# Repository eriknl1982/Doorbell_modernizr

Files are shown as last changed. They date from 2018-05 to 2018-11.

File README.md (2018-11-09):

Imgur

This repository contains sample code and eagle/gerber/STL files for the Doorbell Modernizr I sell on tindie: https://www.tindie.com/products/ErikLemcke/doorbell-modernizr/

The Doorbell Modernizr is a device that can transform your ordinary doorbell (running on 8 - 24v ac) into a "smart" wifi doorbell.
Whenever someone presses your doorbell, the Doorbell Modernizr can send a signal to your home automation system (currently supported: Home assistant, Domoticz and Openhab).

If you want to program the device yourself (for example with the Arduino IDE),provide it with power, plug in a ftdi module and set the dipswitch on the pcb to on.

I use the folowing settings for programming:

- Board: Generic EP8266 module
- Flash mode: QIO
- Flash size: 512K (64K SPIFFS)
- Debugging port: Disabled
- Debug level: None
- IwIP variant: V2 lower memory
- reset method: ck
- crystal frequency: 26Mhz
- Flash frequency: 40Mhz
- CPU frequency: 80Mhz
- Builtin led: 2
- Upload speed: 115200
- Erase flash: Only sketch

If you are going to build it yourself, you will need the folowing parts:

#### To assemble this board, you will need the following parts:
- 1x ESP12f module [(sample)](https://www.aliexpress.com/item/ESP8266-Remote-Serial-WIFI-Transceiver-Wireless-Module-Esp-12-AP-STA-TOP/32646271039.html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,searchweb201602_4_10152_10709_10151_10065_10344_10068_5722815_10342_10343_10340_5722915_10341_5722615_10696_10084_10083_10618_10304_10710_10307_10301_5722715_5711215_10059_308_100031_10103_10624_10623_10622_5711315_5722515_10621_10620,searchweb201603_36,ppcSwitch_5&algo_expid=2d4aea06-a96e-40a3-a231-87c2b62a80c4-1&algo_pvid=2d4aea06-a96e-40a3-a231-87c2b62a80c4&transAbTest=ae803_2&priceBeautifyAB=0)
- 4x 10k resitor, smd size 1206 [(sample)](https://www.aliexpress.com/item/Free-Shipping-100PCS-1206-10K-10K-OHM-1-smd-resistor/1090806202.html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,searchweb201602_4_10152_10709_10151_10065_10344_10068_5722815_10342_10343_10340_5722915_10341_5722615_10696_10084_10083_10618_10304_10710_10307_10301_5722715_5711215_10059_308_100031_10103_10624_10623_10622_5711315_5722515_10621_10620,searchweb201603_36,ppcSwitch_5&algo_expid=709525b8-8593-455c-8efa-07c3f3ce8228-0&algo_pvid=709525b8-8593-455c-8efa-07c3f3ce8228&transAbTest=ae803_2&priceBeautifyAB=0)
- 1x 10k resitor, thru hole [(sample)](https://www.aliexpress.com/store/product/100pcs-set-1-4W-Resistance-1-Metal-Film-Resistor-Pack-Assorted-Kit-1K-2K-4-7K/1504763_32861819464.html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,searchweb201602_4_10152_10151_10065_10344_10068_10342_10343_10340_10341_10696_10084_10083_10618_10304_10307_10820_10821_10301_10843_10059_100031_10103_10624_10623_10622_10621_10620,searchweb201603_51,ppcSwitch_5&algo_expid=e3fd0740-6222-418d-9183-fe36bdfb2f1d-0&algo_pvid=e3fd0740-6222-418d-9183-fe36bdfb2f1d&transAbTest=ae803_2&priceBeautifyAB=0)
- 1x 330r resitor, smd size 1206 [(sample)](https://www.aliexpress.com/item/100Pcs-1206-SMD-resistor-0R-10M-1-2W-0-1-10-100-150-220-330-ohm/32847115923.html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,searchweb201602_4_10152_10709_10151_10065_10344_10068_5722815_10342_10343_10340_5722915_10341_5722615_10696_10084_10083_10618_10304_10710_10307_10301_5722715_5711215_10059_308_100031_10103_10624_10623_10622_5711315_5722515_10621_10620,searchweb201603_36,ppcSwitch_5&algo_expid=03d36d71-9210-4daa-ba6d-0d927a84b877-0&algo_pvid=03d36d71-9210-4daa-ba6d-0d927a84b877&transAbTest=ae803_2&priceBeautifyAB=0)
- 1x 1p dip switch [(sample)](https://www.aliexpress.com/item/10PCS-Lot-DIP-Switch-1P-2-54mm-Toggle-Switch-Red-Snap-Switch/32778200806.html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,searchweb201602_4_10152_10709_10151_10065_10344_10068_5722815_10342_10343_10340_5722915_10341_5722615_10696_10084_10083_10618_10304_10710_10307_10301_5722715_5711215_10059_308_100031_10103_10624_10623_10622_5711315_5722515_10621_10620,searchweb201603_36,ppcSwitch_5&algo_expid=cc64cbff-a764-4662-8452-5fbc674b3830-3&algo_pvid=cc64cbff-a764-4662-8452-5fbc674b3830&transAbTest=ae803_2&priceBeautifyAB=0)
- 2x tactile switch [(sample)](https://www.aliexpress.com/item/THGS-25pcs-Round-Pushbutton-4-Pins-SMD-SMT-Momentary-Tactile-Switch/32721411394.html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,searchweb201602_4_10152_10709_10151_10065_10344_10068_5722815_10342_10343_10340_5722915_10341_5722615_10696_10084_10083_10618_10304_10710_10307_10301_5722715_5711215_10059_308_100031_10103_10624_10623_10622_5711315_5722515_10621_10620,searchweb201603_36,ppcSwitch_5&algo_expid=72ad9c0a-894e-4d0d-a650-c844d18cb295-12&algo_pvid=72ad9c0a-894e-4d0d-a650-c844d18cb295&transAbTest=ae803_2&priceBeautifyAB=0)
- 1x 470uf capacitor [(sample)](https://www.aliexpress.com/item/SMD-electrolytic-capacitor-470UF-6-3V-6-3-7-7MM-VT-type-chip-polarity-temperature-105/32814865187.html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,searchweb201602_4_10152_10709_10151_10065_10344_10068_5722815_10342_10343_10340_5722915_10341_5722615_10696_10084_10083_10618_10304_10710_10307_10301_5722715_5711215_10059_308_100031_10103_10624_10623_10622_5711315_5722515_10621_10620,searchweb201603_36,ppcSwitch_5&algo_expid=fa08a327-d750-4922-8d0c-8a368b171ecc-13&algo_pvid=fa08a327-d750-4922-8d0c-8a368b171ecc&transAbTest=ae803_2&priceBeautifyAB=0)
- 1x 100nf capacitor, SMD size 1206 [(sample)](https://www.aliexpress.com/item/Free-Shipping-100PCS-1206-104-100NF-0-1UF-1206-SMD-capacitance/1096160798.html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,searchweb201602_4_10152_10709_10151_10065_10344_10068_5722815_10342_10343_10340_5722915_10341_5722615_10696_10084_10083_10618_10304_10710_10307_10301_5722715_5711215_10059_308_100031_10103_10624_10623_10622_5711315_5722515_10621_10620,searchweb201603_36,ppcSwitch_5&algo_expid=ae9db756-53ad-4fca-853d-d6855f03eda6-0&algo_pvid=ae9db756-53ad-4fca-853d-d6855f03eda6&transAbTest=ae803_2&priceBeautifyAB=0)
- 1x 2pin screw terminal [(sample)](https://www.aliexpress.com/item/20-PCS-KF301-5-0-2P-blue-KF301-3P-Pitch-5-0mm-KF301-2P-Straight-Pin/32833138976.html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,searchweb201602_4_10152_10709_10151_10065_10344_10068_5722815_10342_10343_10340_5722915_10341_5722615_10696_10084_10083_10618_10304_10710_10307_10301_5722715_5711215_10059_308_100031_10103_10624_10623_10622_5711315_5722515_10621_10620,searchweb201603_36,ppcSwitch_5&algo_expid=dd191ab4-0937-468a-a91b-19ac53064bd2-2&algo_pvid=dd191ab4-0937-468a-a91b-19ac53064bd2&transAbTest=ae803_2&priceBeautifyAB=0)
- 1x 6pin female header [(sample)](https://www.aliexpress.com/item/40pcs-2-54MM-6Pin-11MM-Long-Needle-Female-Header-Strip-Stackable-Header-for-arduino-W5100-6p/32668087711.html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,searchweb201602_4_10152_10709_10151_10065_10344_10068_5722815_10342_10343_10340_5722915_10341_5722615_10696_10084_10083_10618_10304_10710_10307_10301_5722715_5711215_10059_308_100031_10103_10624_10623_10622_5711315_5722515_10621_10620,searchweb201603_36,ppcSwitch_5&algo_expid=c0a98dbf-f354-486c-be51-a9068dfd1d38-12&algo_pvid=c0a98dbf-f354-486c-be51-a9068dfd1d38&transAbTest=ae803_2&priceBeautifyAB=0)
- 1x HT7333 LDO [(sample)](https://www.aliexpress.com/item/10PCS-HT7333-A-SOT-89-HT7333-1-SOT89-HT7333-7333-1-SMD-7333A-1-new-and/32818420909.html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,searchweb201602_4_10152_10709_10151_10065_10344_10068_5722815_10342_10343_10340_5722915_10341_5722615_10696_10084_10083_10618_10304_10710_10307_10301_5722715_5711215_10059_308_100031_10103_10624_10623_10622_5711315_5722515_10621_10620,searchweb201603_36,ppcSwitch_5&algo_expid=5d51c538-7dd5-42bd-8e93-c66127f056bf-0&algo_pvid=5d51c538-7dd5-42bd-8e93-c66127f056bf&transAbTest=ae803_2&priceBeautifyAB=0)
- 1x 1N4148 diode, smd size 1206 [(sample)](https://www.aliexpress.com/item/100pcs-1206-1N4148W-T4-1N4148-SOD-123-Switching-Diode/32354597825.html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,searchweb201602_4_10152_10709_10151_10065_10344_10068_5722815_10342_10343_10340_5722915_10341_5722615_10696_10084_10083_10618_10304_10710_10307_10301_5722715_5711215_10059_308_100031_10103_10624_10623_10622_5711315_5722515_10621_10620,searchweb201603_36,ppcSwitch_5&algo_expid=7cf2de10-d2b9-41eb-a268-300ace100396-0&algo_pvid=7cf2de10-d2b9-41eb-a268-300ace100396&transAbTest=ae803_2&priceBeautifyAB=0)
- 1x PC817 Optocoupler [(sample)](https://www.aliexpress.com/item/100PCS-PC817C-DIP-PC817-C-DIP4-PC817-C-new-and-original-IC-free-shipping/32847601895.html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,searchweb201602_4_10152_10709_10151_10065_10344_10068_5722815_10342_10343_10340_5722915_10341_5722615_10696_10084_10083_10618_10304_10710_10307_10301_5722715_5711215_10059_308_100031_10103_10624_10623_10622_5711315_5722515_10621_10620,searchweb201603_36,ppcSwitch_5&algo_expid=e8d061c3-7004-462e-899c-a522d5885630-1&algo_pvid=e8d061c3-7004-462e-899c-a522d5885630&transAbTest=ae803_2&priceBeautifyAB=0)
- 1x 5.5 x 2.1 mm Female DC Power Jack Plug Socket [sample](https://www.aliexpress.com/item/10Pcs-PCB-Mount-5-5-x-2-1-mm-Female-DC-Power-Jack-Plug-Socket-Connector/32813661863.html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,searchweb201602_4_10152_10709_10151_10065_10344_10068_5722815_10342_10343_10340_5722915_10341_5722615_10696_10084_10083_10618_10304_10710_10307_10301_5722715_5711215_10059_308_100031_10103_10624_10623_10622_5711315_5722515_10621_10620,searchweb201603_36,ppcSwitch_5&algo_expid=b89433cb-84ea-4f2c-b110-90657c1acf5a-26&algo_pvid=b89433cb-84ea-4f2c-b110-90657c1acf5a&transAbTest=ae803_2&priceBeautifyAB=0)
- 1x 5v power supply [sample](https://www.aliexpress.com/item/1PCS-High-quality-AC-100V-240V-Converter-Switching-power-adapter-DC-5V-2A-2000MA-Supply-EU/32496043021.html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,searchweb201602_4_10152_10709_10151_10065_10344_10068_5722815_10342_10343_10340_5722915_10341_5722615_10696_10084_10083_10618_10304_10710_10307_10301_5722715_5711215_10059_308_100031_10103_10624_10623_10622_5711315_5722515_10621_10620,searchweb201603_36,ppcSwitch_5&algo_expid=0f10a11c-3fea-4ce8-9680-a6fa20d2b76d-3&algo_pvid=0f10a11c-3fea-4ce8-9680-a6fa20d2b76d&transAbTest=ae803_2&priceBeautifyAB=0)
- 1x MB6S bridge rectifier [sample](https://www.aliexpress.com/item/Free-shipping-20pcs-600V-0-5A-SOP-4-SMD-rectifier-diode-bridge-mb6s/32336867082.html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,searchweb201602_3_10152_10151_10065_10344_10068_5723115_5722815_10342_10343_10340_5722915_10341_5722615_10696_10084_10083_10618_10304_10307_10820_10301_10821_5722715_10843_10059_100031_10103_10624_10623_10622_5722515_10621_10620,searchweb201603_50,ppcSwitch_5&algo_expid=d8bc8f3c-cd8b-4e61-a706-30cb63aab87a-0&algo_pvid=d8bc8f3c-cd8b-4e61-a706-30cb63aab87a&transAbTest=ae803_2&priceBeautifyAB=0)

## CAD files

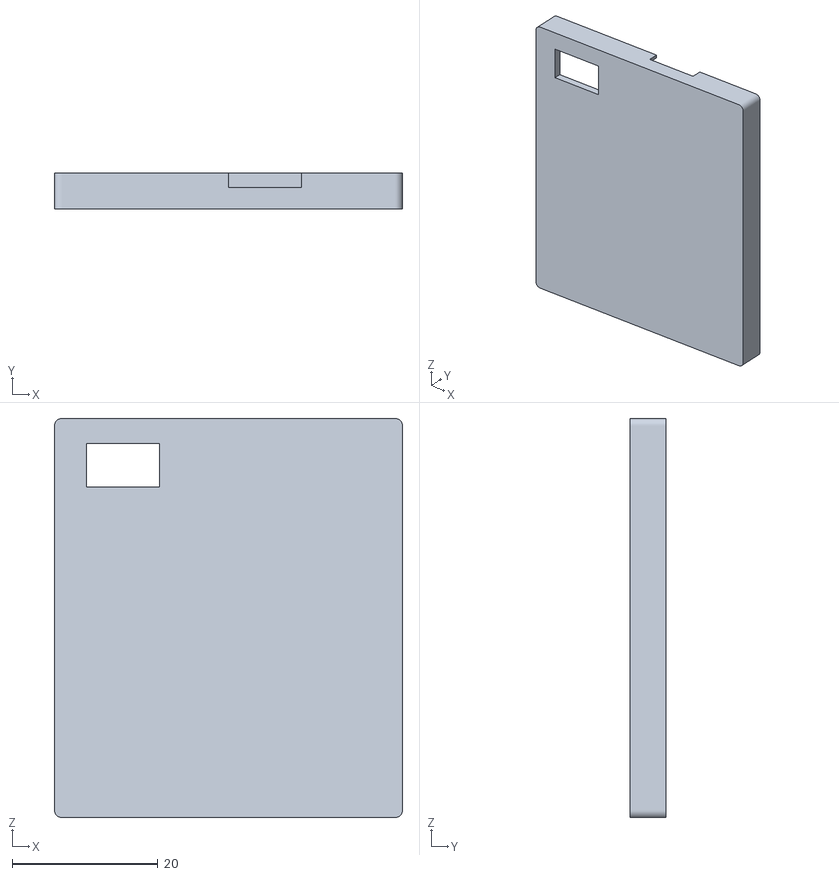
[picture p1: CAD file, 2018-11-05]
3d print housing files/for v2.0/top.STL
47.8 x 5.00 x 54.8

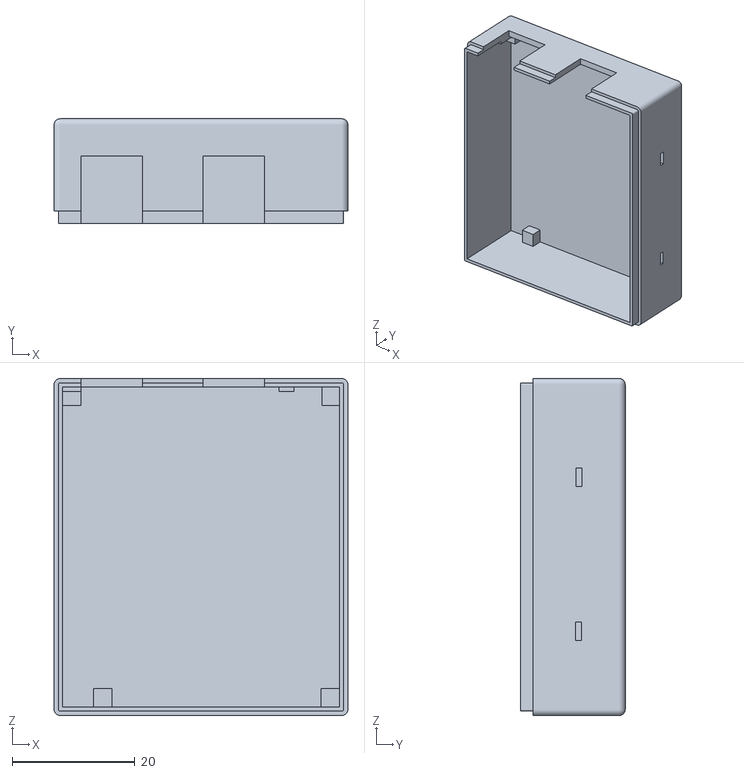
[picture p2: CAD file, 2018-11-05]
3d print housing files/for v2.0/base.STL
47.8 x 17.0 x 54.8

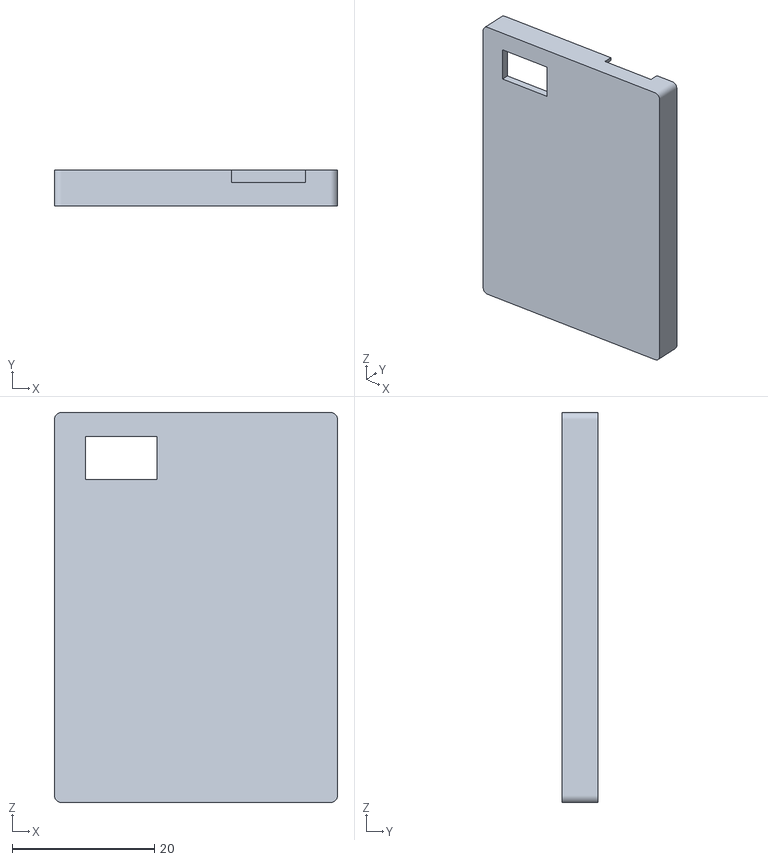
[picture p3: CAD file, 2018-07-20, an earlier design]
3d print housing files/for v1.1/top.STL
39.8 x 5.00 x 54.8

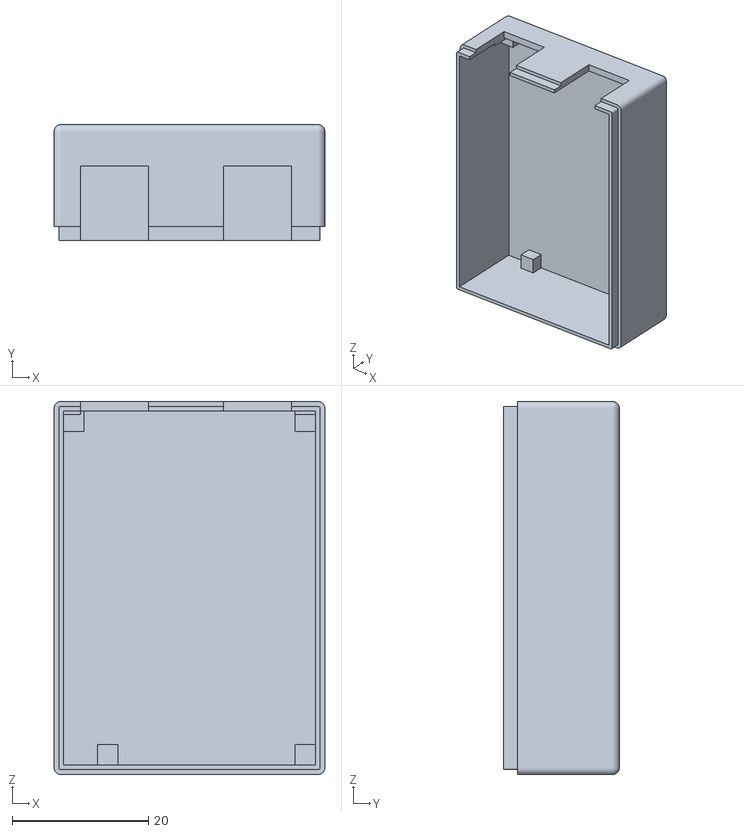
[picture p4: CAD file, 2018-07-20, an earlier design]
3d print housing files/for v1.1/base.STL
39.8 x 17.0 x 54.8

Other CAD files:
3d print housing files/for v1.2 & 1.2a/base.STL
3d print housing files/for v1.2 & 1.2a/top.STL

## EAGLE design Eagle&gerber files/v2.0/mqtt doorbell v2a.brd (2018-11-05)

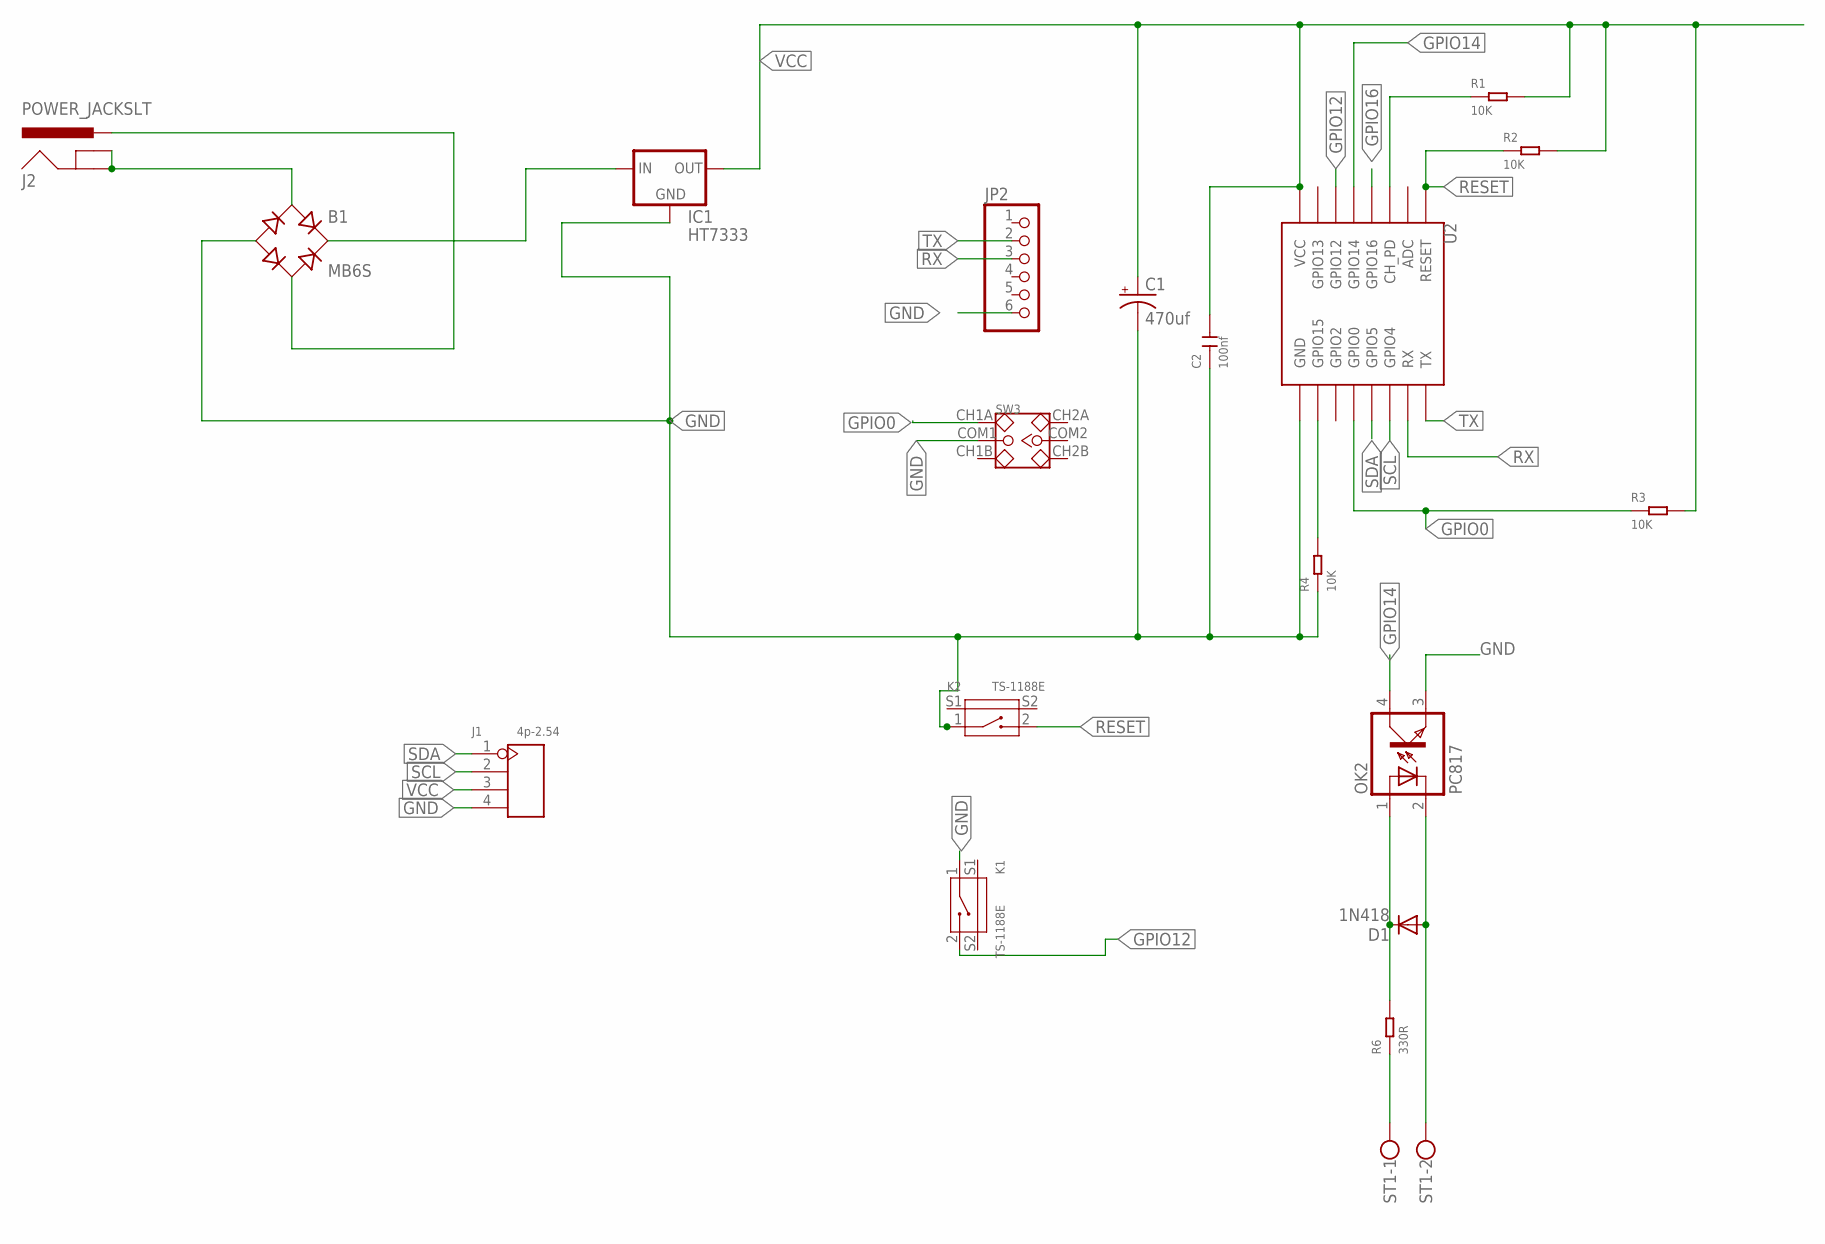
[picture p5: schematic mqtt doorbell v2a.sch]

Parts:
B1: MB6S; SOIC-4
C1: 470uf; PANASONIC_D
C2: 100nf; C0603
D1: 1N418; SOD-123_MINI-SMA
IC1: HT7333; SOT-89
J1: 4p-2.54; H4-2.54
J2: POWER_JACKSLT; POWER_JACK_SLOT
JP2: PINHD-1X6; 1X06
K1, K2: TS-1188E; SW4-SMD-7.0X3.5X3.5MM-90D
OK2: PC817; SOP-4-2.54
R1, R2, R3, R4: 10K; R0603
R6: 330R; R0603
ST1: W237-102
SW3: SMD-TOGGLE-SWITCH-2CH(2X3P-7X3.5MM); SW6-2.54-SMD-7.0X3.5X1.5MM
U2: ESP12SMD; ESP12-SMD

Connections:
GND: B1.-, C1.-, C2.1, IC1.2 (GND), J1.4, JP2.6, K1.1, K2.1, OK2.3 (EMIT), R4.1, SW3.COM1, U2.GND
GPIO0: R3.1, SW3.CH1A, U2.GPIO0
GPIO12: K1.2, U2.GPIO12
GPIO14: OK2.4 (COL), U2.GPIO14
GPIO16: U2.GPIO16
L1: B1.+, IC1.3 (IN), IC1.4 (IN)
unnamed: B1.~2 (AC2), J2.PWR
unnamed: D1.C, OK2.1 (A), R6.2
unnamed: D1.A, OK2.2 (C), ST1.2
unnamed: R1.1, U2.CH_PD
unnamed: R6.1, ST1.1
unnamed: R4.2, U2.GPIO15
unnamed: B1.~1 (AC1), J2.GND@1 (GNDBREAK), J2.GND@2 (GND)
RESET: K2.2, R2.1, U2.RESET
RX: JP2.3, U2.RXD0 (RX)
SCL: J1.2, U2.GPIO4
SDA: J1.1, U2.GPIO5
TX: JP2.2, U2.TXD0 (TX)
VCC: C1.+, C2.2, IC1.1 (OUT), J1.3, R1.2, R2.2, R3.2, U2.VCC

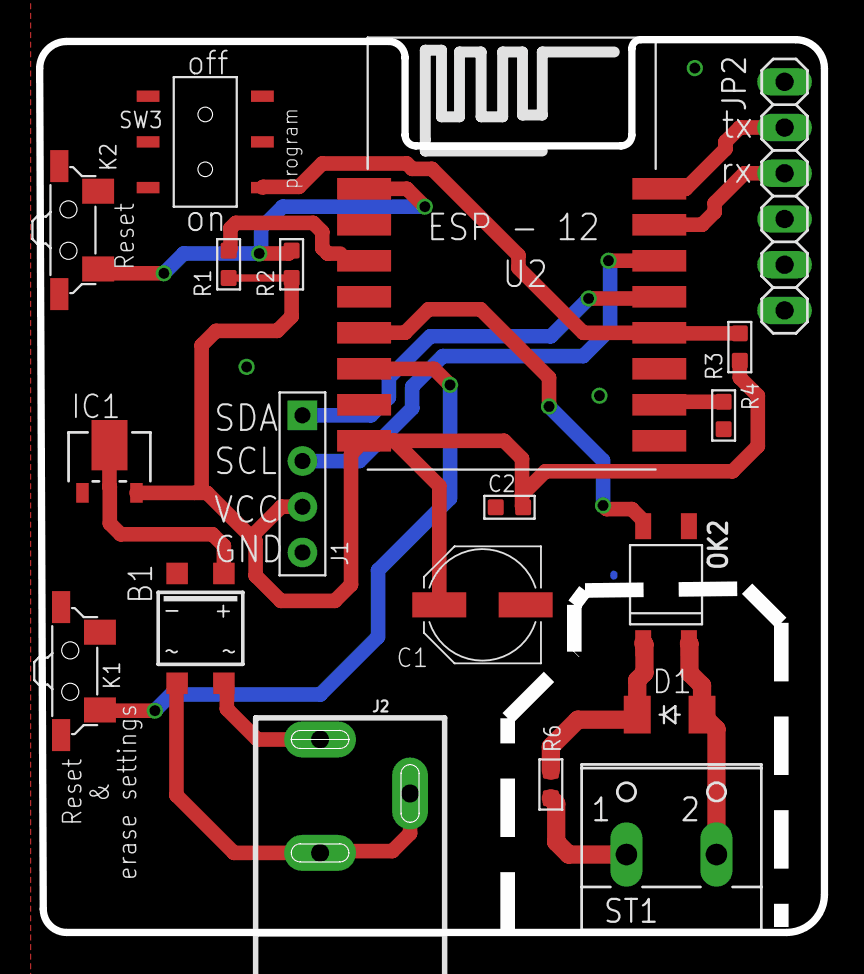
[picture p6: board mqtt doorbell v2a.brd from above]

Board: 2 copper layers, 43.6 x 49.6 mm, 19 parts (0 on the bottom side), 18 nets.

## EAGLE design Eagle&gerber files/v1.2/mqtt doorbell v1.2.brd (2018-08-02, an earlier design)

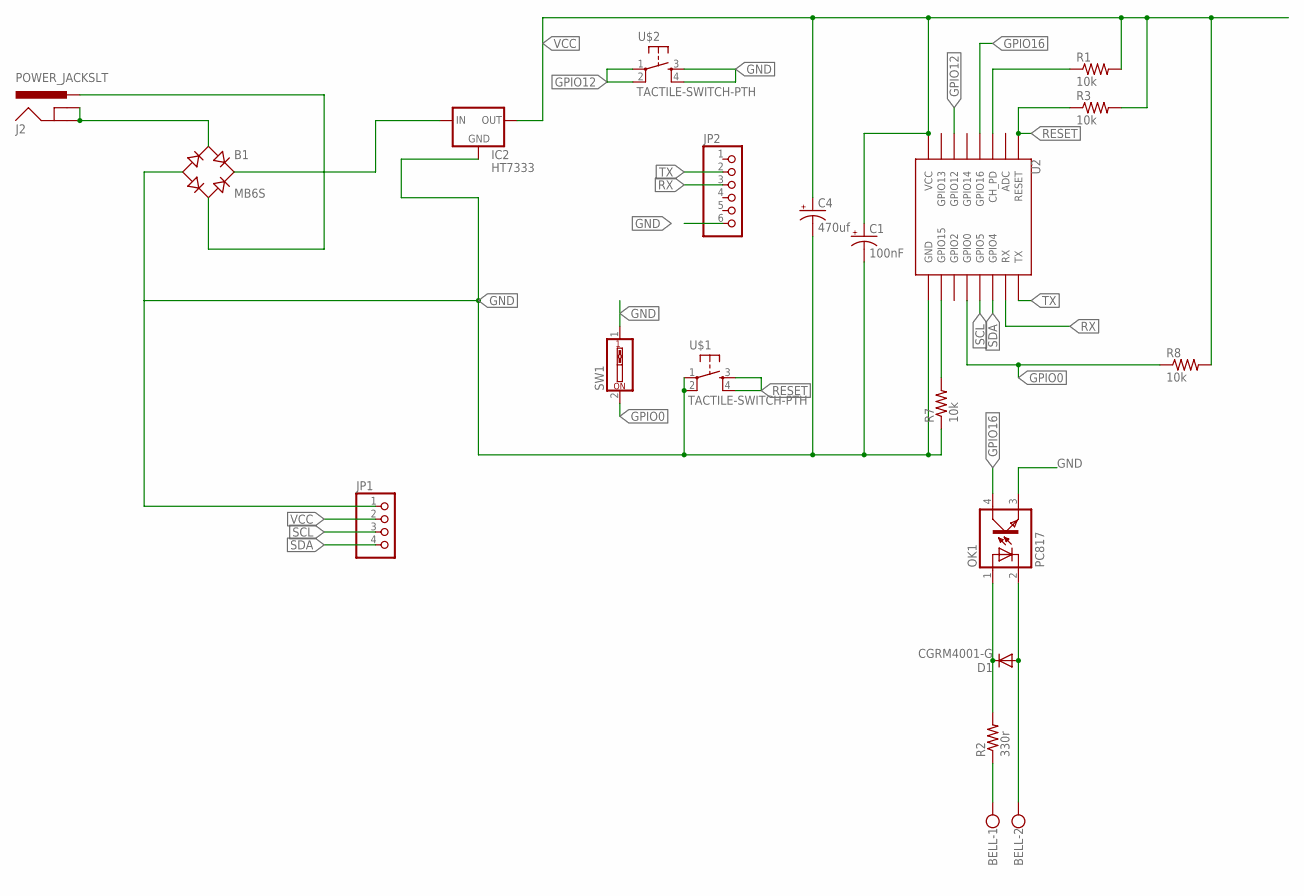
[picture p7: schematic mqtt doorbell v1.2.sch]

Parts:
B1: MB6S; SOIC-4
BELL: W237-102
C1: 100nF; EIA3216
C4: 470uf; PANASONIC_D
D1: CGRM4001-G; SOD-123_MINI-SMA
IC2: HT7333; SOT-89
J2: POWER_JACKSLT; POWER_JACK_SLOT
JP1: PINHD-1X4; 1X04
JP2: PINHD-1X6; 1X06
OK1: PC817; DIL04
R1, R3, R7, R8: 10k; 1206
R2: 330r; 1206
SW1: SW_DIP-1; EDG-01
U2: ESP12SMD; ESP12-SMD
U$1, U$2: TACTILE-SWITCH-PTH; TAC-SWITCH-PTH

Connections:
GND: B1.-, C1.C (-), C4.-, IC2.2 (GND), JP1.1, JP2.6, OK1.3 (EMIT), R7.1, SW1.1, U2.GND, U$1.1, U$1.2, U$2.3, U$2.4
GPIO0: R8.1, SW1.2, U2.GPIO0
GPIO12: U2.GPIO12, U$2.1, U$2.2
GPIO16: OK1.4 (COL), U2.GPIO16
unnamed: B1.~2 (AC2), J2.PWR
unnamed: D1.C, OK1.1 (A), R2.2
unnamed: BELL.2, D1.A, OK1.2 (C)
unnamed: R1.1, U2.CH_PD
unnamed: BELL.1, R2.1
unnamed: R7.2, U2.GPIO15
unnamed: B1.~1 (AC1), J2.GND@1 (GNDBREAK), J2.GND@2 (GND)
unnamed: B1.+, IC2.3 (IN), IC2.4 (IN)
RESET: R3.1, U2.RESET, U$1.3, U$1.4
RX: JP2.3, U2.RXD0 (RX)
SCL: JP1.3, U2.GPIO5
SDA: JP1.4, U2.GPIO4
TX: JP2.2, U2.TXD0 (TX)
VCC: C1.A (+), C4.+, IC2.1 (OUT), JP1.2, R1.2, R3.2, R8.2, U2.VCC

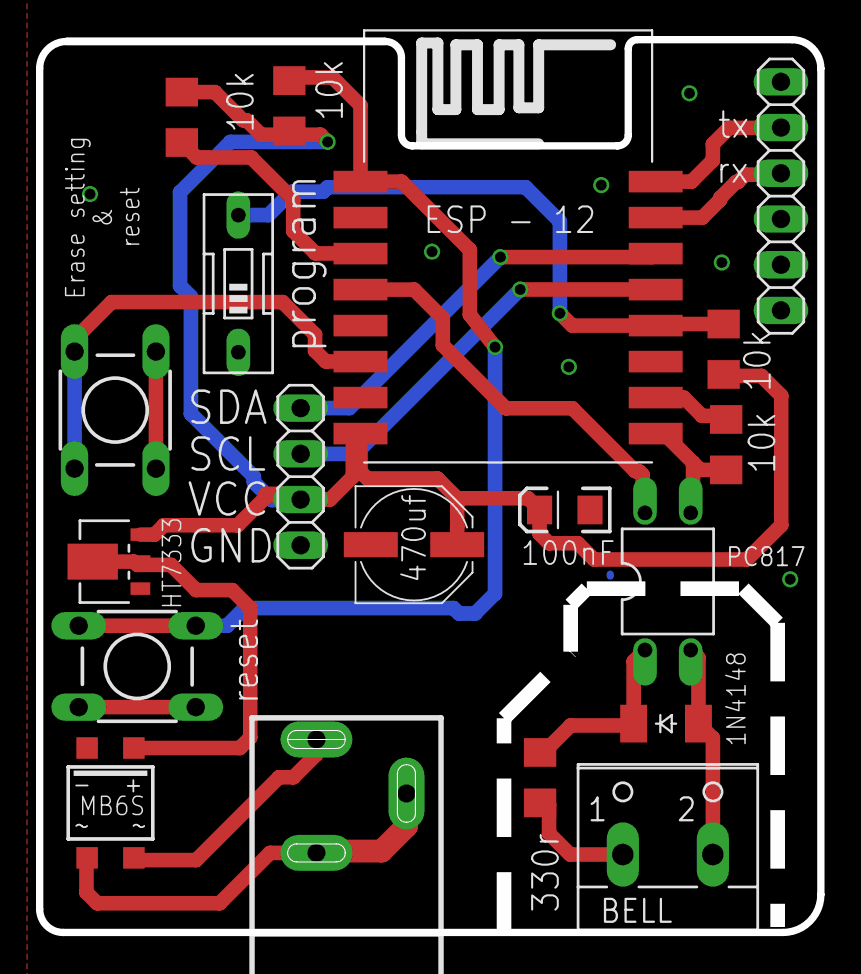
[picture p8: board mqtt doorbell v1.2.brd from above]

Board: 2 copper layers, 43.4 x 49.6 mm, 19 parts (0 on the bottom side), 18 nets.

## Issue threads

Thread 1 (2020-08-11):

OK2: Footprint incorrect

bbjunkie, 2020-08-11:
The footprint for OK2 Optocoupler on the V2.0 board is too small and does not fit the device quoted in the readme.md

bbjunkie, 2020-08-11:
After measuring, it seems that the footprint is for SOP-4 package not DIP

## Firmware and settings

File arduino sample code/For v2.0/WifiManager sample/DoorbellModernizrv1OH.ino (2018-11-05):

/***************************************************************************
 Code to use with MQTT wifi doorbell, see https://www.tindie.com/products/ErikLemcke/mqtt--wifi-doorbell-with-esp8266/
 Created by Erik Lemcke 22-06-2018


 This code can be used from the arduino library, you will need the following libraries:
 https://github.com/tzapu/WiFiManager     Included in this repository (src folder)
 https://github.com/bblanchon/ArduinoJson
 https://github.com/knolleary/pubsubclient
 https://github.com/esp8266/Arduino/tree/master/libraries/ESP8266mDNS

 credits:

 https://tzapu.com/                   for the awesome WiFiManger library
 https://github.com/esp8266/Arduino   fopr the ESP8266 arduino core
 https://arduinojson.org/             for the ArduinoJson library
 https://pubsubclient.knolleary.net/  for the mqtt library
  
 ***************************************************************************/
#include <fs.h>                   //this needs to be first, or it all crashes and burns...
#import "index.h"

#include <ESP8266WiFi.h>          //https://github.com/esp8266/Arduino

//needed for library
#include <DNSServer.h>
#include <ESP8266WebServer.h>
#include "src/WiFiManager.h" 

#include <ArduinoJson.h>          //https://github.com/bblanchon/ArduinoJson
#include <PubSubClient.h>
#include <base64.h>
#include <ESP8266HTTPClient.h>

//libs for lcd
#include <Wire.h>  
#include "SSD1306Wire.h" 
#include "logo.h"

int doorbellState = 0;
int resetState = 0;
const int doorbellPin = 14;

WiFiClient espClient;
HTTPClient http; 
PubSubClient client(espClient);

WiFiManager wifiManager;
ESP8266WebServer server(80);
SSD1306Wire  display(0x3c, 4, 5);

unsigned long previousMillis = 0;       

DNSServer dnsServer; //Needed for captive portal when device is already connected to a wifi network

//extra parameters
char mqtt_server[40];
char mqtt_port[6] ;
char mqtt_username[40];
char mqtt_password[40];
char mqtt_topic[40];
char mqtt_status[60] = "unknown";

char dz_idx[5];
char oh_itemid[40];

//flag for saving data
bool shouldSaveConfig = false;
bool apstarted = false;

//callback notifying us of the need to save config
void saveConfigCallback () {
  Serial.println("Should save config");
  shouldSaveConfig = true;
}

void configModeCallback (WiFiManager *myWiFiManager) {
  Serial.println("Connection to previous set wifi failed. Erasing settings before becoming AP");
  //SPIFFS.format();

  display.clear();
  display.setTextAlignment(TEXT_ALIGN_LEFT);
  display.setFont(ArialMT_Plain_10);
  display.drawString(0, 0, "Doorbell modernizr");
  display.drawString(0, 20, "in configuration mode");
  display.drawString(0, 30, "Connect to access point"); 
  display.drawString(0, 40, "\"Doorbell modernizr\""); 
  display.drawString(0, 50, "to configure"); 
  display.display();
}

//Handle webserver root request
void handleRoot() {
  Serial.println("Handling webserver request");
  String addy = server.client().remoteIP().toString();
  Serial.println(addy);
  
  //determine if this user is connected to the AP or comming from the network the device is connected to
  //when connected to AP, configuration is not allowed
  if (addy == "192.168.4.2"){
      server.send(200, "text/html", "The doorbell modernizr can be configured on address http:// " + WiFi.localIP().toString() + " when connected to wifi network " + WiFi.SSID());
  } else {
    String configPage = config_page;
    configPage.replace("{v}", "Doorbell modernizr configuration");
    configPage.replace("{1}", mqtt_server);
    configPage.replace("{2}", mqtt_port);
    configPage.replace("{3}", mqtt_username);
    configPage.replace("{4}", mqtt_password);
    configPage.replace("{5}", mqtt_topic);
    configPage.replace("{6}", mqtt_status);
    configPage.replace("{7}", dz_idx);
    configPage.replace("{8}", oh_itemid);
    
    server.send(200, "text/html", configPage);
  }
}

void saveSettings() {
  Serial.println("Handling webserver request savesettings");

  //store the updates values in the json config file
    DynamicJsonBuffer jsonBuffer;
    JsonObject& json = jsonBuffer.createObject();
    json["mqtt_server"] = server.arg("mqtt_server");
    json["mqtt_port"] = server.arg("mqtt_port");
    json["mqtt_username"] = server.arg("mqtt_username");
    json["mqtt_password"] = server.arg("mqtt_password");
    json["mqtt_topic"] = server.arg("mqtt_topic");

    json["dz_idx"] = server.arg("dz_idx");
    json["oh_itemid"] = server.arg("oh_itemid");
   
    File configFile = SPIFFS.open("/config.json", "w");
    if (!configFile) {
      Serial.println("failed to open config file for writing");
    }

    json.printTo(Serial);
    json.printTo(configFile);
    configFile.close();

    //put updated parameters into memory so they become effective immediately
    server.arg("mqtt_server").toCharArray(mqtt_server,40);
    server.arg("mqtt_port").toCharArray(mqtt_port,40);
    server.arg("mqtt_username").toCharArray(mqtt_username,40);
    server.arg("mqtt_password").toCharArray(mqtt_password,40);
    server.arg("mqtt_topic").toCharArray(mqtt_topic,40);
    server.arg("dz_idx").toCharArray(dz_idx,40);
    server.arg("oh_itemid").toCharArray(oh_itemid,40);
   
    server.send(200, "text/html", "Settings have been saved. You will be redirected to the configuration page in 5 seconds <meta http-equiv=\"refresh\" content=\"5; url=/\" />");
    
    //mqtt settings might have changed, let's reconnect to the mqtt server if one is configured
    if (strlen(mqtt_topic) != 0){
      Serial.println("mqtt topic set, need to connect");
      reconnect();
    }
}

void setup() {
  

  Serial.begin(115200);
  Serial.println();

  //initialize lcd display
  display.init();
  display.flipScreenVertically();
  display.setFont(ArialMT_Plain_10);

  pinMode(doorbellPin, INPUT_PULLUP);
  pinMode(12, INPUT_PULLUP);
  pinMode(BUILTIN_LED, OUTPUT);
 
  //read configuration from FS json
  Serial.println("mounting FS...");

  if (SPIFFS.begin()) {
    Serial.println("mounted file system");
    if (SPIFFS.exists("/config.json")) {
      //file exists, reading and loading
      Serial.println("reading config file");
      File configFile = SPIFFS.open("/config.json", "r");
      if (configFile) {
        Serial.println("opened config file");
        size_t size = configFile.size();
        // Allocate a buffer to store contents of the file.
        std::unique_ptr<char[]> buf(new char[size]);

        configFile.readBytes(buf.get(), size);
        DynamicJsonBuffer jsonBuffer;
        JsonObject& json = jsonBuffer.parseObject(buf.get());
        json.printTo(Serial);
        if (json.success()) {
          Serial.println("\nparsed json");

          strcpy(mqtt_server, json["mqtt_server"]);
          strcpy(mqtt_port, json["mqtt_port"]);
          strcpy(mqtt_username, json["mqtt_username"]);
          strcpy(mqtt_password, json["mqtt_password"]);
          strcpy(mqtt_topic, json["mqtt_topic"]);

          strcpy(dz_idx, json["dz_idx"]);
          strcpy(oh_itemid, json["oh_itemid"]);

        } else {
          Serial.println("failed to load json config");
        }
      }
    }
  } else {
    Serial.println("failed to mount FS");
  }
  //end read

  WiFiManagerParameter custom_mqtt_server("server", "ip address", mqtt_server, 40);
  WiFiManagerParameter custom_mqtt_port("port", "port", mqtt_port, 5);
  WiFiManagerParameter custom_mqtt_username("username", "username", mqtt_username, 40);
  WiFiManagerParameter custom_mqtt_password("password", "password", mqtt_password, 40);
  WiFiManagerParameter custom_mqtt_topic("topic", "mqtt topic", mqtt_topic, 40);

  WiFiManagerParameter custom_dz_idx("dzidx", "Domoticz idx", dz_idx, 5);
  WiFiManagerParameter custom_oh_itemid("ohitemid", "OpenHAB itenId", oh_itemid, 40);

  WiFiManagerParameter custom_text("<p>Fill the folowing values with your Home assistant / Domoticz / OpenHAB information. Username and password are optional</p>");
  wifiManager.addParameter(&custom_text);

  //set config save notify callback
  wifiManager.setSaveConfigCallback(saveConfigCallback);

  wifiManager.setAPCallback(configModeCallback);

  wifiManager.addParameter(&custom_mqtt_server);
  wifiManager.addParameter(&custom_mqtt_port);
  wifiManager.addParameter(&custom_mqtt_username);
  wifiManager.addParameter(&custom_mqtt_password);

  WiFiManagerParameter custom_text1("<p>Fill the folowing field with your MQTT topic for Home assistant</p>");
  wifiManager.addParameter(&custom_text1);
  
  wifiManager.addParameter(&custom_mqtt_topic);

  WiFiManagerParameter custom_text2("<p>Fill the folowing field with your IDX value for Domoticz</p>");
  wifiManager.addParameter(&custom_text2);
    
  wifiManager.addParameter(&custom_dz_idx);

  WiFiManagerParameter custom_text3("<p>Fill the folowing field with your itemId for OpenHAB</p>");
  wifiManager.addParameter(&custom_text3);

  wifiManager.addParameter(&custom_oh_itemid);

  //fetches ssid and pass and tries to connect
  //if it does not connect it starts an access point with the specified name
  //and goes into a blocking loop awaiting configuration
  display.clear();
  display.setTextAlignment(TEXT_ALIGN_LEFT);
  display.setFont(ArialMT_Plain_10);
  display.drawString(0, 0, "Doorbell modernizr");
  display.drawString(0, 20, "Attempting to connect");
  display.drawString(0, 30, "to wifi network"); 
  display.drawString(0, 40 ,WiFi.SSID());
  display.display();    
    
  if (!wifiManager.autoConnect("Doorbell modernizr")) {
    Serial.println("failed to connect and hit timeout");
    delay(3000);
    //reset and try again
    ESP.reset();
    delay(5000);
  }

  //if you get here you have connected to the WiFi
  Serial.println("connected...!");

  //Define url's for webserver 
  server.on("/", handleRoot);
  server.on("/saveSettings", saveSettings);
  server.onNotFound([]() {
    handleRoot();
  });
  server.begin();

  //read updated parameters
  strcpy(mqtt_server, custom_mqtt_server.getValue());
  strcpy(mqtt_port, custom_mqtt_port.getValue());
  strcpy(mqtt_username, custom_mqtt_username.getValue());
  strcpy(mqtt_password, custom_mqtt_password.getValue());
  strcpy(mqtt_topic, custom_mqtt_topic.getValue());

  strcpy(dz_idx, custom_dz_idx.getValue());
  strcpy(oh_itemid, custom_oh_itemid.getValue());

  //save the custom parameters to FS
  if (shouldSaveConfig) {
    Serial.println("saving config");
    DynamicJsonBuffer jsonBuffer;
    JsonObject& json = jsonBuffer.createObject();
    json["mqtt_server"] = mqtt_server;
    json["mqtt_port"] = mqtt_port;
    json["mqtt_username"] = mqtt_username;
    json["mqtt_password"] = mqtt_password;
    json["mqtt_topic"] = mqtt_topic;
    json["dz_idx"] = dz_idx;
    json["oh_itemid"] = oh_itemid;

    File configFile = SPIFFS.open("/config.json", "w");
    if (!configFile) {
      Serial.println("failed to open config file for writing");
    }

    json.printTo(Serial);
    json.printTo(configFile);
    configFile.close();
    //end save
  }

  client.setServer(mqtt_server, atoi(mqtt_port));

  Serial.println("Doorbell modernizr ip on " + WiFi.SSID() + ": " + WiFi.localIP().toString());


}


//MQTT reconnect function
void reconnect() {

  
  client.disconnect();
  client.setServer(mqtt_server, atoi(mqtt_port));
  Serial.print("Attempting MQTT connection to ");
  Serial.print(mqtt_server);
  Serial.print(" on port ");
  Serial.print(mqtt_port);
  Serial.print("...");

  display.clear();

    display.setTextAlignment(TEXT_ALIGN_LEFT);
    display.setFont(ArialMT_Plain_10);
    display.drawString(0, 0, "Doorbell modernizr");
    display.drawString(0, 20, "Attempting MQtt connection");
    display.display();
  
  if (client.connect("ESP8266Client", mqtt_username, mqtt_password)) {
     Serial.println("connected");
     String("<div style=\"color:green;float:left\">connected</div>").toCharArray(mqtt_status,60);
     Serial.print("sending 'off' message to ");
     Serial.print(mqtt_server);
     Serial.print(" on port ");
     Serial.print(mqtt_port);
     Serial.print(" with topic ");
     Serial.println(mqtt_topic);
     client.publish(mqtt_topic, "off" , true);
   } else {
     Serial.print("failed, rc=");
     String("<div style=\"color:red;float:left\">connection failed</div>").toCharArray(mqtt_status,60);
     Serial.print(client.state());
     Serial.println(" try again in 5 seconds");

    display.clear();
    display.setTextAlignment(TEXT_ALIGN_LEFT);
    display.setFont(ArialMT_Plain_10);
    display.drawString(0, 0, "Doorbell modernizr");
    display.drawString(0, 20, "Attempting Mqtt connection");
    display.drawString(0, 30, "Status: Failed");
    display.drawString(0, 40, "reconfigure at");
    display.drawString(0, 50, "http://" + WiFi.localIP().toString());
    display.display();

    unsigned long previousMillis1 = 0;

     //connection failed, Go into a (non-blocking) loop until we are connected 
     while (!client.connected()) {
        resetstate();
         server.handleClient();  //call to handle webserver connection needed, because the while loop will block the processor
         unsigned long currentMillis1 = millis();
         if(currentMillis1 - previousMillis1 >= 5000) {
         previousMillis1 = currentMillis1;
         Serial.print("Attempting MQTT connection...");
          if (client.connect("ESP8266Client", mqtt_username, mqtt_password)) {
                Serial.println("connected");
                String("<div style=\"color:green;float:left\">connected</div>").toCharArray(mqtt_status,60);
             } else {
                     String("<div style=\"color:red;float:left\">connection failed</div>").toCharArray(mqtt_status,60);
                Serial.print("failed, rc=");
                Serial.print(client.state());
                Serial.println(" try again in 5 seconds");
             }
         }
      }
   }
}

long lastMsg = 0;

//Initialize a reset if pin 12 is low
void resetstate (){
   resetState = digitalRead(12);
   if (resetState == LOW){
    Serial.println("It seems someone wants to go for a reset...");

    display.clear();
    display.setTextAlignment(TEXT_ALIGN_LEFT);
    display.setFont(ArialMT_Plain_10);
    display.drawString(0, 0, "Doorbell modernizr");
    display.drawString(0, 20, "Keep reset button pressed");
    display.drawString(0, 30, "for 5 seconds to reset");
    display.drawString(0, 40, "and erase all settings");
    display.display();
    
    int count = 0;

    //Flash the led for 5 seconds
    while (count < 25 && digitalRead(12) == LOW) {
      digitalWrite(BUILTIN_LED, HIGH);   
      delay(100);                      
      digitalWrite(BUILTIN_LED, LOW);    
      delay(100);                      
      count ++;
    }
  
    resetState = digitalRead(12);
    //See if they still want to go for it
    if (resetState == LOW){
       Serial.println("Let's do it");
       SPIFFS.format();
       wifiManager.resetSettings();
       delay(500);
       ESP.restart();  
    } else {
      drawDefaultScreen();
      Serial.println("They chickened out...");
      Serial.println("Now starting AP");

      
      boolean result = false;
      while (result == false){
        Serial.println("Attempting to start AP");
        result = WiFi.softAP("Doorbell modernizr online" );  
      }
      
      if(result == true)
      {
        dnsServer.start(53, "*", WiFi.softAPIP());
          
        apstarted = true;
        previousMillis =  millis();
        Serial.println("AP IP address: " +  WiFi.softAPIP().toString());
      }
    }
  }
}

void drawDefaultScreen(){
  display.clear();
  display.setTextAlignment(TEXT_ALIGN_LEFT);
  display.setFont(ArialMT_Plain_10);
  display.drawString(30, 0, "configure at");
  display.drawString(30, 10, "http://" + WiFi.localIP().toString());
  display.drawFastImage(0, 0, 128, 64, Logo_bits);
  display.display();
}

void loop() {

  //if a AP is started, kill it after 3 minutes
  if (apstarted == true){
    unsigned long currentMillis = millis();
    if (currentMillis - previousMillis >= 300000) {
      previousMillis = currentMillis;
      Serial.println("Stopping the AP, 3 minutes are past!");
      WiFi.softAPdisconnect(false);
      apstarted = false;    
    }
  }
 
  resetstate();
  
  if (strlen(mqtt_topic) != 0){
       //try to reconnect to mqtt server if connection is lost
    if (!client.connected()) { 
      reconnect();
    }
    client.loop();
  }
  
  server.handleClient();
  dnsServer.processNextRequest();
   
  doorbellState = digitalRead(doorbellPin);
  resetState = digitalRead(12);
  drawDefaultScreen();  
    
 if ( doorbellState == LOW ) {
    display.clear();
    display.setTextAlignment(TEXT_ALIGN_LEFT);
    display.setFont(ArialMT_Plain_10);
    display.drawString(0, 0, "Doorbell modernizr");
    display.drawString(0, 20, "Doorbell is pressed");
    display.drawString(0, 30, "sending 'on' message to");
    display.drawString(0, 40, String(mqtt_server) + " on port " + String(mqtt_port));
    display.drawString(0, 50, "with topic " + String(mqtt_topic));
    display.display();

    if (strlen(mqtt_topic) != 0){
      client.publish(mqtt_topic, "on" , true);
      Serial.print("Doorbell is pressed!, sending 'on' message to ");
      Serial.print(mqtt_server);
      Serial.print(" on port ");
      Serial.print(mqtt_port);
      Serial.print(" with topic ");
      Serial.println(mqtt_topic);
      
  
      //wait 5 seconds, then publish the off message
      delay( 5000 );
  
      display.clear();
      display.setTextAlignment(TEXT_ALIGN_LEFT);
      display.setFont(ArialMT_Plain_10);
      display.drawString(0, 0, "Doorbell modernizr");
  
      display.drawString(0, 30, "sending 'off' message to");
      display.drawString(0, 40, String(mqtt_server) + " on port " + String(mqtt_port));
      display.drawString(0, 50, "with topic " + String(mqtt_topic));
      display.display();
      
      Serial.print("sending 'off' message to ");
      Serial.print(mqtt_server);
      Serial.print(" on port ");
      Serial.print(mqtt_port);
      Serial.print(" with topic ");
      Serial.println(mqtt_topic);
      client.publish(mqtt_topic, "off" , true);    
    }
   if (strlen(dz_idx) != 0){
    if (espClient.connect(mqtt_server,atoi(mqtt_port))){
      Serial.println("sending 'on' message to Domiticz");
      espClient.print("GET /json.htm?type=command&param=udevice&idx=");
      espClient.print(String(dz_idx));
      espClient.print("&nvalue=1");
      
      if (strlen(mqtt_username) != 0){
        espClient.print("&username=");
        espClient.print(base64::encode(mqtt_username));
        espClient.print("&password=");
        espClient.print(base64::encode(mqtt_password));
      }
      
      espClient.println(" HTTP/1.1");
      espClient.print("Host: ");
      espClient.print(String(mqtt_server));
      espClient.print(":");
      espClient.println(String(mqtt_port));
      espClient.println("User-Agent: doorbell-modernizr");
      espClient.println("Connection: close");
      espClient.println();
      espClient.stop();
   } else {
     Serial.println("connect failed");
   }
      //wait 5 seconds, then publish the off message
      delay( 5000 );
    if (espClient.connect(mqtt_server,atoi(mqtt_port))){
        Serial.println("sending 'off' message to Domiticz");
        espClient.print("GET /json.htm?type=command&param=udevice&idx=");
        espClient.print(String(dz_idx));
        espClient.print("&nvalue=0");
  
         if (strlen(mqtt_username) != 0){
          espClient.print("&username=");
          espClient.print(base64::encode(mqtt_username));
          espClient.print("&password=");
          espClient.print(base64::encode(mqtt_password));
        }
        
        espClient.println(" HTTP/1.1");
        espClient.print("Host: ");
        espClient.print(String(mqtt_server));
        espClient.print(":");
        espClient.println(String(mqtt_port));
        espClient.println("User-Agent: doorbell-modernizr");
        espClient.println("Connection: close");
        espClient.println();
        espClient.stop();
     } else {
       Serial.println("connect failed");
     } 
   }

   // OpenHAB
   if (strlen(oh_itemid) != 0){

      Serial.println("sending 'ON' message to openHAB");
      http.begin("http://" + String(mqtt_server) + ":" + String(mqtt_port) +"/rest/items/" + String(oh_itemid)); 
      http.POST("ON");
      http.end();

      delay(5000);

      Serial.println("sending 'OFF' message to openHAB");
      http.begin("http://" + String(mqtt_server) + ":" + String(mqtt_port) +"/rest/items/" + String(oh_itemid)); 
      http.POST("OFF"); 
      http.end();
    
   }  
  }
}

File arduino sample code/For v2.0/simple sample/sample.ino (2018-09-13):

#include <ESP8266WiFi.h>
#include <PubSubClient.h>

#define wifi_ssid "YOUR WIFI NAME"
#define wifi_password "YOUR WIFI PASSWORD"

#define mqtt_server "YOUR HOME ASSISTANT MQTT IP"
#define mqtt_user "YOUR HOME ASSISTANT USERNAME"
#define mqtt_password "YOUR HOME ASSISTANT PASSWORD"

#define doorbell_topic "hal/doorbell" //change to whatever you like to use a s topic

int doorbellState = 0;
const int doorbellPin = 14;

WiFiClient espClient;
PubSubClient client(espClient);

void setup() {
  Serial.begin(115200);

  setup_wifi();
  client.setServer(mqtt_server, 1883);
  pinMode(doorbellPin, INPUT_PULLUP);

  WiFi.mode(WIFI_STA); //don't be a AP
 }

void setup_wifi() {
  delay(10);
  // We start by connecting to a WiFi network
  Serial.println();
  Serial.print("Connecting to ");
  Serial.println(wifi_ssid);

  WiFi.mode(WIFI_STA);
  WiFi.begin(wifi_ssid, wifi_password);

  while (WiFi.status() != WL_CONNECTED) {
    delay(500);
    Serial.print(".");
  }

  Serial.println("");
  Serial.println("WiFi connected");
  Serial.println("IP address: ");
  Serial.println(WiFi.localIP());
}

void reconnect() {
  // Loop until we're reconnected
  while (!client.connected()) {
    Serial.print("Attempting MQTT connection...");
    // Attempt to connect
    // If you do not want to use a username and password, change next line to
    // if (client.connect("ESP8266Client")) {
    if (client.connect("ESP8266Client", mqtt_user, mqtt_password)) {
      Serial.println("connected");
    } else {
      Serial.print("failed, rc=");
      Serial.print(client.state());
      Serial.println(" try again in 5 seconds");
      // Wait 5 seconds before retrying
      delay(5000);
    }
  }
}

void loop() {
  if (!client.connected()) {
    reconnect();
  }
  client.loop();
 
doorbellState = digitalRead(doorbellPin);

 if ( doorbellState == LOW ) {
    // Put your code here.  e.g. connect, send, disconnect.
    client.publish(doorbell_topic, "on" , true);
    Serial.println("Doorbell is pressed!");

    //wait 5 seconds, then publish the off message
    delay( 5000 );
    client.publish(doorbell_topic, "off" , true);
  }
}

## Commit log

2018-05-18 Added schematics
    [mqtt doorbell v1.GBL, mqtt doorbell v1.GBO, mqtt doorbell v1.GBP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]
2018-06-18 added wifimanager sample
2018-07-08 eagle & gerber files for v1.1
    [mqtt doorbell v1.1.GBL, mqtt doorbell v1.1.GBO, mqtt doorbell v1.1.GBP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]
2018-07-20 added 3d print files
    [base.STL, top.STL]
2018-08-02 Files for v1.2
    [mqtt doorbell v1.2.GBL, mqtt doorbell v1.2.GBO, mqtt doorbell v1.2.GBP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]
2018-08-09 3d print files for v1.2
    [base.STL, top.STL]
2018-09-13 sample source for v1.2a
2018-09-13 files for v1.2a
    [base.STL, top.STL]
2018-11-05 files for v2.0
    [base.STL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]

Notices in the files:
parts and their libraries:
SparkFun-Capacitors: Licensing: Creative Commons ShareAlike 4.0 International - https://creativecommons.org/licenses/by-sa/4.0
